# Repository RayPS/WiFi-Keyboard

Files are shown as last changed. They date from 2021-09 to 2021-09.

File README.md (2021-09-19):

# WiFi-Keyboard
A remote control usb keyboard http server device based on ESP8266 & CH9328

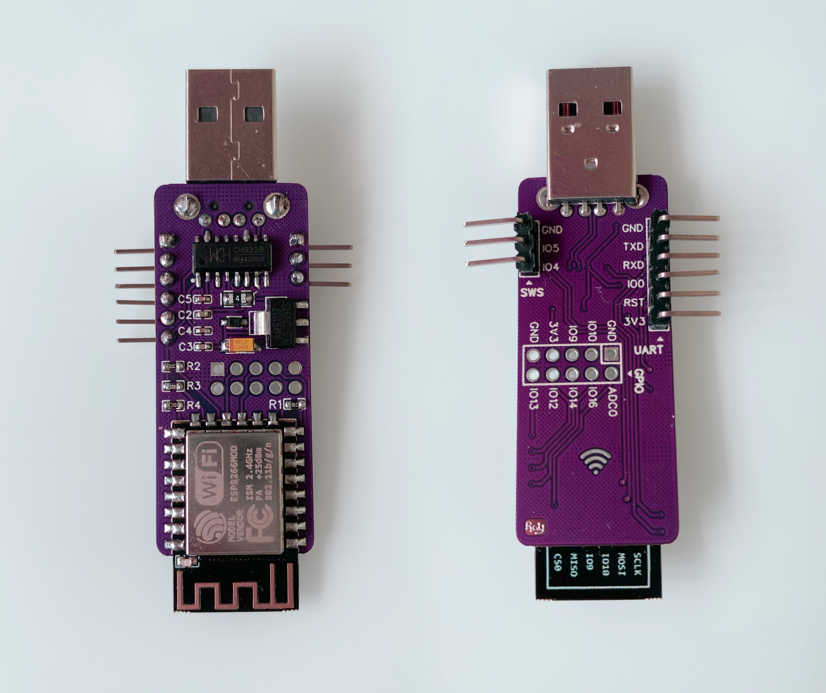
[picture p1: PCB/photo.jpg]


## Schematics

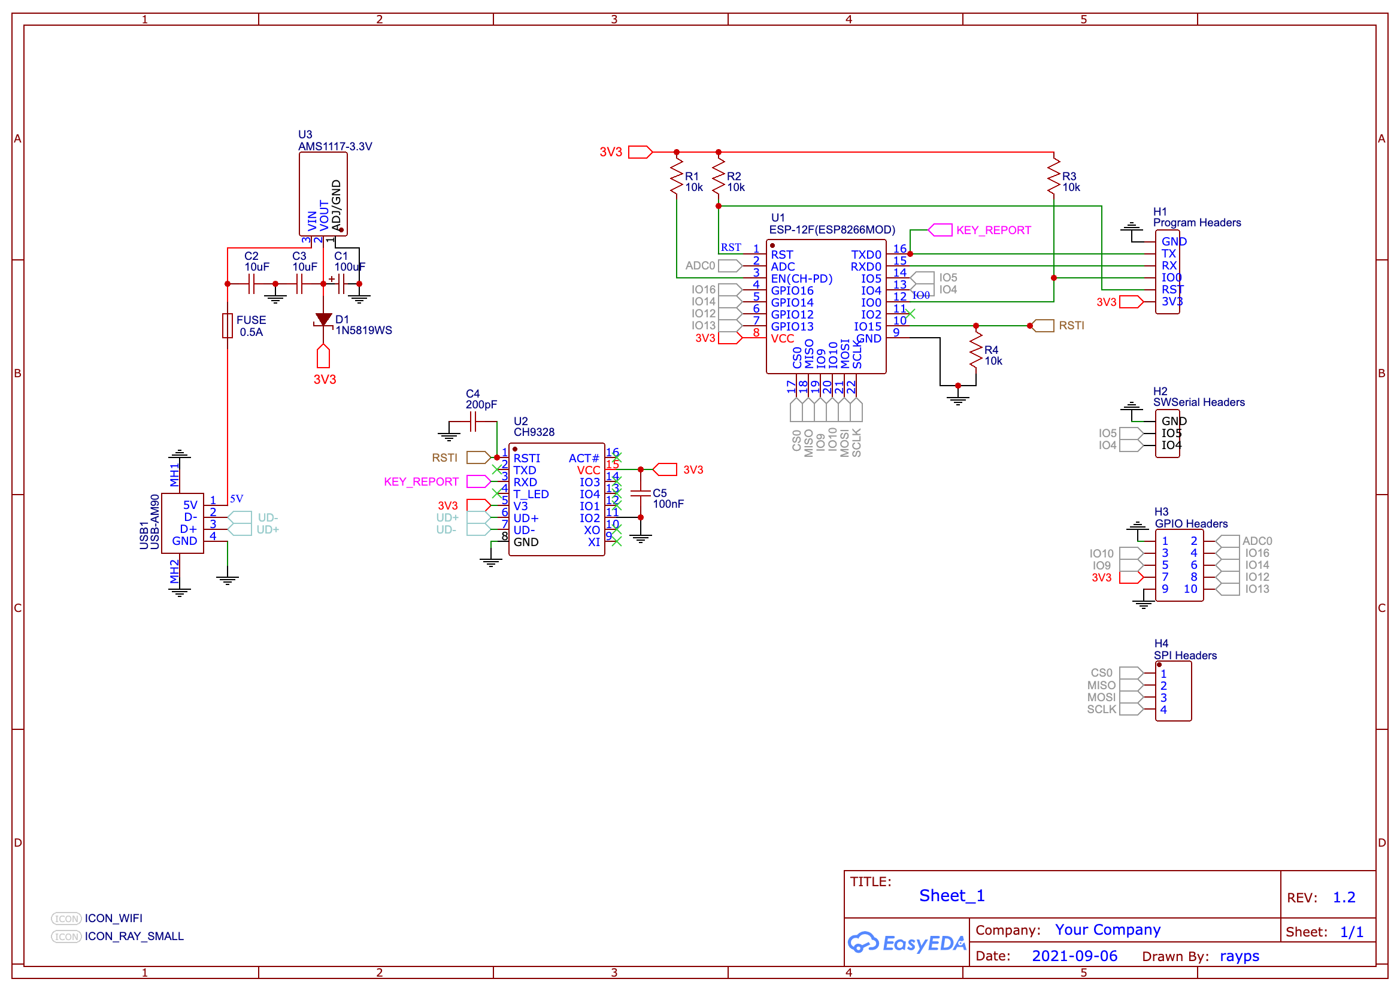
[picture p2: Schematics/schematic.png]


## PCB

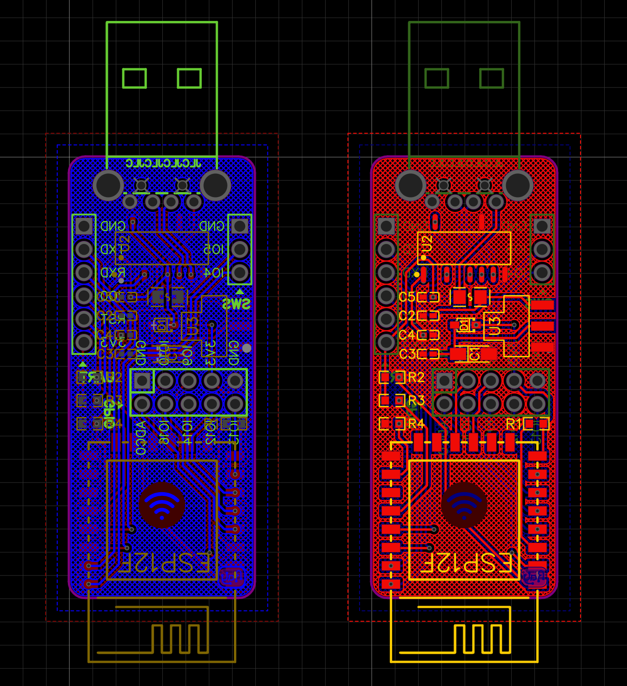
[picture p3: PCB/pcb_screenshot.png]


## Development
(An UART adapter with `DTR` & `RTS` port is required)
1. Open this project in PlatformIO
2. Connect the device to your computer using an UART adapter
3. Build and upload to the device

#### Connections
| UART Adapter | This Device |
| - | - |
| 3V3 | 3V3 |
| GND | GND |
| RX | TX |
| TX | RX |
| RTS | RST |
| DTR | IO0 |

## Usage
1. Plug the device to the host machine
2. Connect to the device WiFi named `Keyboard`, a config portal should appear
3. Choose to connect the same WiFi as your client machine network
4. Open [http://keyboard.local/](http://keyboard.local/) 

#### Use as HTTP API
```bash
curl -X "POST" "http://keyboard.local/" \
     -H 'Content-Type: application/json; charset=utf-8' \
     -d $'{"input": "HelloWorld"}'
```
or

`POST http://keyboard.local/?input=helloworld`

#### Notes
At the current stage of development, only printable characters are supported.

To support other keys I will need to make something like DuckyScript Parser.

But that's beyond the purpose of this project, the goal of this project is for game consoles such as Nintendo Switch/Playstation/Xbox etc.

## LED status
| LED | Status |
| - | - |
| Blinking | No network is connected |
| Light | Successfully connected to a network and MDNS is initialized |
| Dark after blink | Successfully connected to a network but MDNS failed |

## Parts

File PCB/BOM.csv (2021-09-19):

ID | Name | Designator | Footprint | Quantity
1 | ICON | ICON1 | ICON_WIFI | 1
2 | 10uF | C2,C3 | C0402 | 2
3 | 200pF | C4 | C0402 | 1
4 | CH9328 | U2 | CH9328_MOD | 1
5 | 100nF | C5 | C0402 | 1
6 | 1N5819WS | D1 | SOD-323_L1.8-W1.3-LS2.5-RD | 1
7 | 0.5A | FUSE | F0805 | 1
8 | 10k | R1,R2,R3,R4 | R0603 | 4
9 | ESP-12F(ESP8266MOD) | U1 | WIFIM-SMD_ESP-12F-ESP8266MOD | 1
10 | 100uF | C1 | CAP-SMD_L3.2-W1.6-R-RD | 1
11 | AMS1117-3.3V | U3 | SOT-223-4_MOD | 1
12 | ICON | ICON2 | ICON_RAY_SMALL | 1
13 | Program Headers | H1 | HDR-TH_6P-P2.54-V-M-1 | 1
14 | SWSerial Headers | H2 | HDR-TH_3P-P2.54-V-M-1 | 1
15 | GPIO Headers | H3 | HDR-TH_10P-P2.54-V-M-R2-C5-S2.54 | 1
16 | USB-AM90 | USB1 | USB-A-TH_AM90 | 1

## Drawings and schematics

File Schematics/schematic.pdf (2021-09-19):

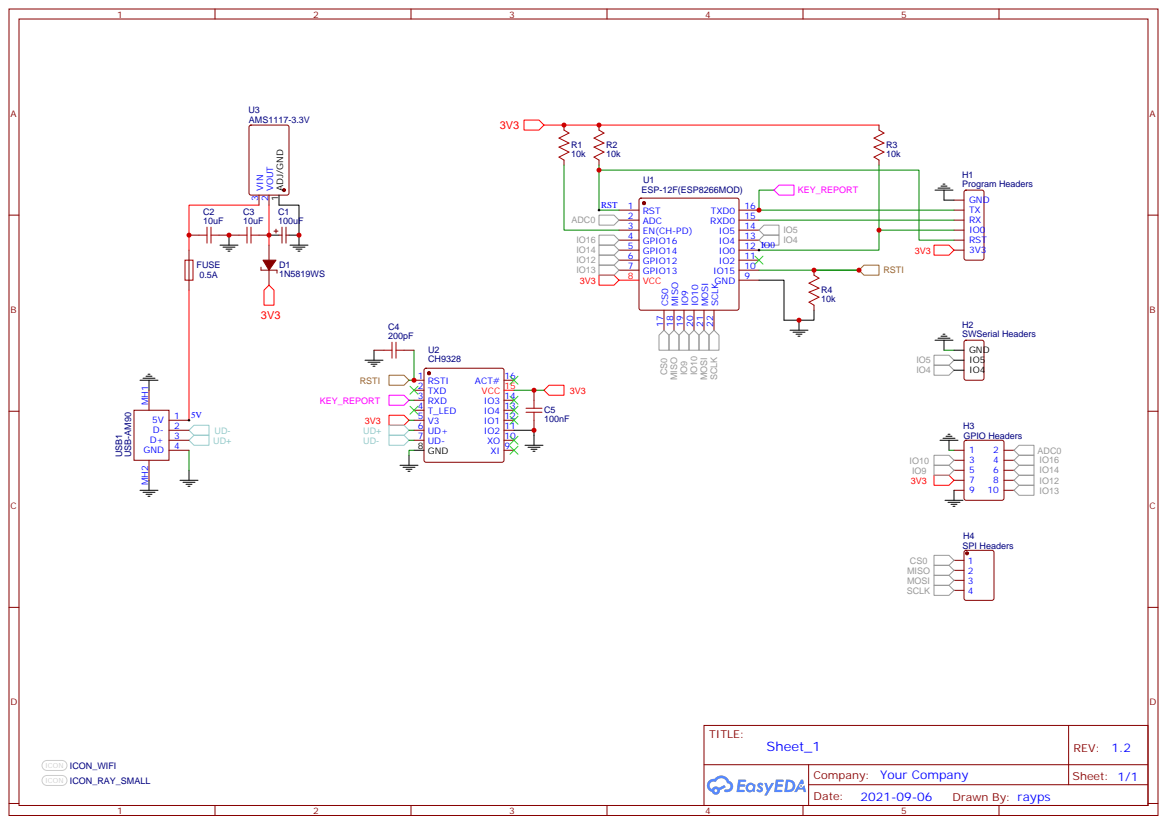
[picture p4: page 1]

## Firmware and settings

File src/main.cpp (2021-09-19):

#include <Arduino.h>
#include <SoftwareSerial.h>
#include <ESP8266WiFi.h>
#include <ESP8266WebServer.h>
#include <ESP8266mDNS.h>
#include <WiFiManager.h>
#include <Ticker.h>
#include <CH9328Keyboard.h>

#define SWSP_TX D1
#define SWSP_RX D2
SoftwareSerial swSerial;

WiFiManager wm;
ESP8266WebServer server(80);

#define CH9328_RST D8
const int KEY_DELAY = 24; //ms delay between key presses

bool ledState = HIGH;

Ticker wifiStatusLED ([]() {
  if (WiFi.status() != WL_CONNECTED) {
    ledState = !ledState;
    digitalWrite(LED_BUILTIN, ledState);
  }
}, 100, 0, MILLIS);

void type(String text) {
  for (unsigned int i = 0; i < text.length(); i++) {
    Keyboard.press(text[i]); delay(KEY_DELAY);
    Keyboard.releaseAll(); delay(KEY_DELAY);
  }
}

const String html = "\
<html>\
  <body>\
    <h1>Keyboard</h1>\
    <form>\
      <input type=\"text\" id=\"input\" name=\"input\">\
      <input type=\"submit\">\
    </form>\
  <script type=\"text/javascript\">\
    document.forms[0].onsubmit = async(e) => {\
      e.preventDefault();\
      const params = new URLSearchParams([...new FormData(e.target).entries()]);\
      fetch(\"/\", { method: \"POST\", body: params });\
      const response = await new Response(params).text();\
      console.log(response);\
    }\
  </script>\
  </body>\
</html>";


void handleRequest() {
  if (server.method() != HTTP_POST) {
    server.send(200, "text/html", html);
  } else {
    String input = server.arg("input");
    swSerial.print("Input: "); swSerial.println(input);
    type(input);
    server.send(200);
  } 
}

void setup() {
  pinMode(LED_BUILTIN, OUTPUT);
  pinMode(13, INPUT_PULLUP);
  swSerial.begin(9600, SWSERIAL_8N1, SWSP_RX, SWSP_TX, false);
  WiFi.mode(WIFI_STA);

  wm.setConfigPortalBlocking(false);
  wm.setMinimumSignalQuality(50);
  wm.setRemoveDuplicateAPs(false);
  wm.setTimeout(10);
  wm.setDarkMode(true);
  wm.setSaveConfigCallback([]() {
    swSerial.println("Saving WiFi config! Restarting device...");
    ESP.restart();
  });
  wm.setBreakAfterConfig(true);

  wifiStatusLED.start();

  if (wm.autoConnect("Keyboard")) {
    swSerial.println("Connected! IP address: " + WiFi.localIP().toString());
    if (MDNS.begin("keyboard")) {
      MDNS.addService("http", "tcp", 80);
      swSerial.println("MDNS responder started: http://keyboard.local/");
      digitalWrite(LED_BUILTIN, LOW);
    } else {
      wifiStatusLED.stop();
      swSerial.println("MDNS responder failed!");
      digitalWrite(LED_BUILTIN, HIGH);
    }
    Keyboard.begin(&Serial, CH9328_RST, 9600);

    server.on("/", handleRequest);
    server.begin();
  }
}

void loop() {
  wm.process();
  MDNS.update();
  wifiStatusLED.update();
  server.handleClient();
}
